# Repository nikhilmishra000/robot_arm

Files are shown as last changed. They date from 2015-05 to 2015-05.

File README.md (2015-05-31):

This is the CAD designs and some sample code for a 6 DOF robot arm I designed and built during fall 2014 while working for Professor Pieter Abbeel at the Robot Learning Lab at UC Berkeley.
It is made of laser-cut MDF and uses hobby servos for a total cost of ~$500. The SolidWorks files include some of the bearings, but no motors, angle-brackets, or springs (for counter-weights).

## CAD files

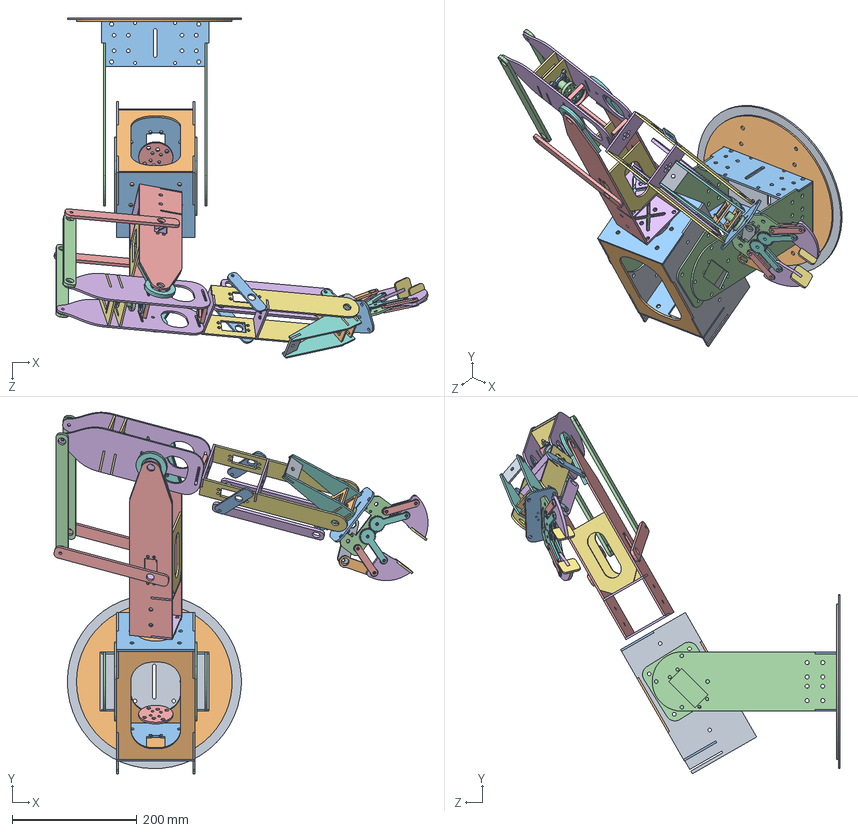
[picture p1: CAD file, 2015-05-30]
sw/arm.SLDASM
600.4 x 580.6 x 546.5 mm
base2
base1
base3 x 2
base4 x 2
upper_arm1 x 2
upper_arm2_(1,2) x 2
upper_arm3 x 2
upper_arm4 x 4
shoulder1 x 2
shoulder2 x 2
shoulder3_(1,2) x 2
shoulder4 x 2
shoulder5
elbow1 x 2
elbow2_(1,2) x 2
elbow3_(1,2,3)
1 x 1.245 super thin bearing x 2
.5 x .75 non flanged bearing x 2
servo shaft hub x 2
forearm1 x 2
forearm2 x 2
wrist1 x 2
wrist3
wrist2_(1,2) x 2
palm1
palm2
finger1 x 4
finger2 x 2
finger3 x 2
finger4 x 4
link1
link2
wrist_link2 x 2
elbow_link1 x 2
elbow_link2 x 2
wrist_link1 x 2

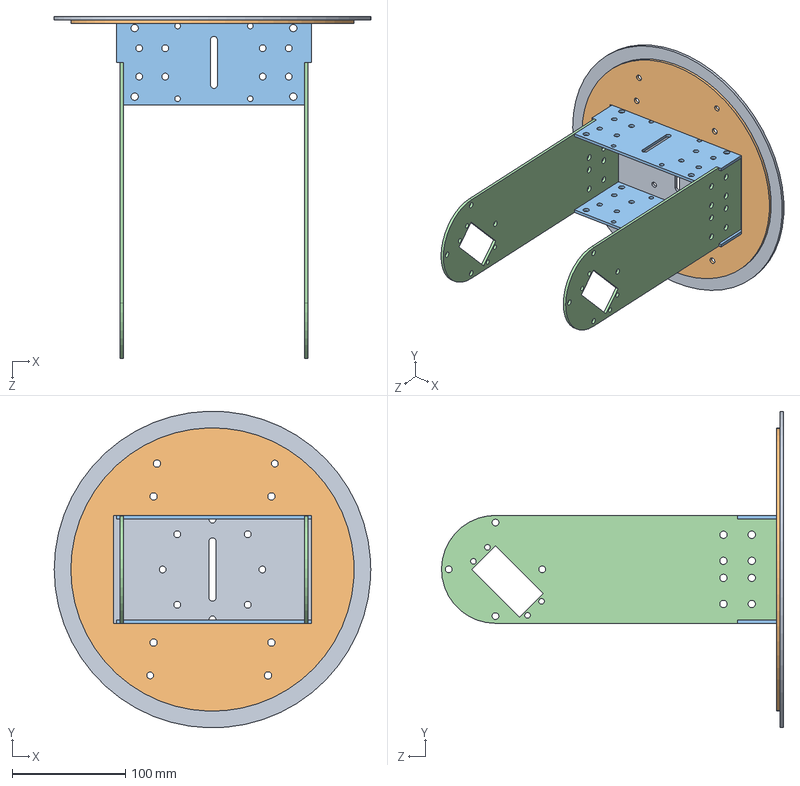
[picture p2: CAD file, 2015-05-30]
sw/base/BASE.SLDASM
279.4 x 279.3 x 301.8 mm
base2
base1
base3 x 2
base4 x 2

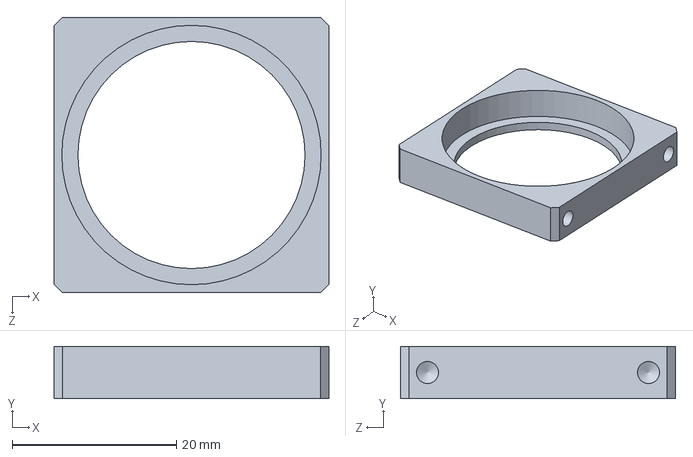
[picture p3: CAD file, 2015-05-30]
sw/bearings/bearing_mount2.SLDASM
33.5 x 6.35 x 33.5 mm

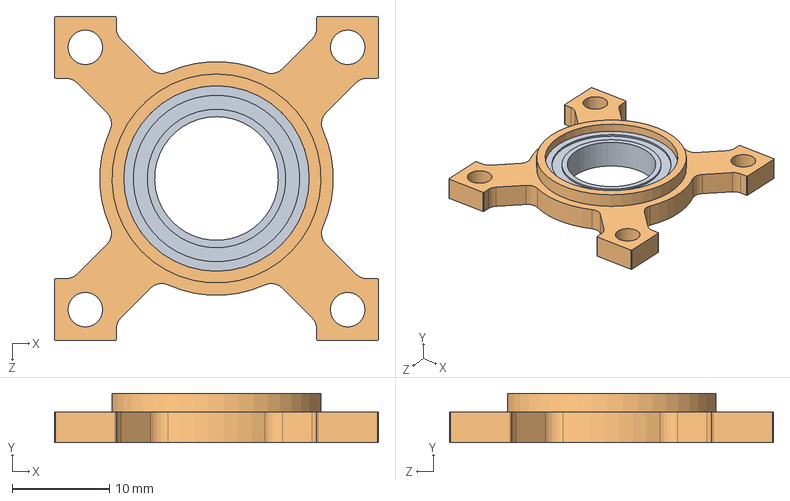
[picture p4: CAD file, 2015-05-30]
sw/bearings/bearing mount.SLDASM
33.3 x 5.08 x 33.3 mm
.5 x .75 non flanged bearing

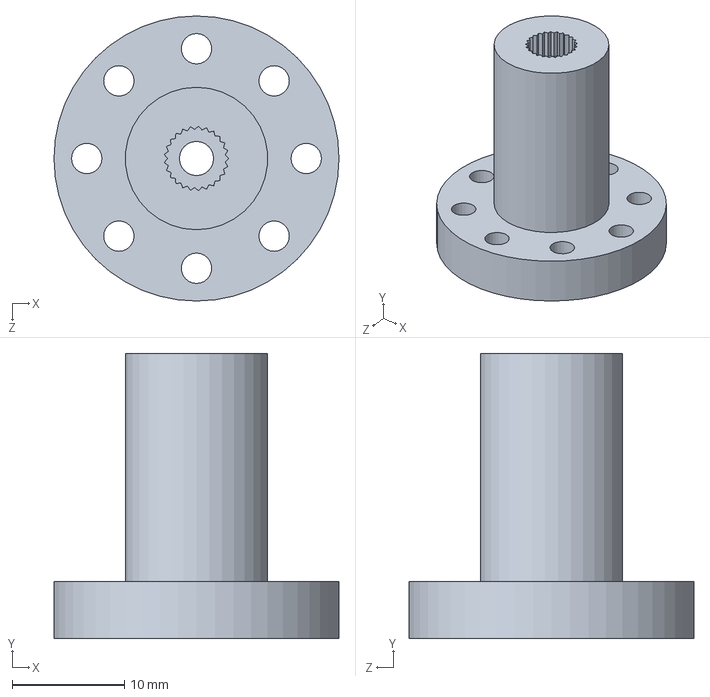
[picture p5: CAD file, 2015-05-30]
sw/bearings/servo shaft hub.SLDPRT
25.4 x 25.4 x 25.4 mm

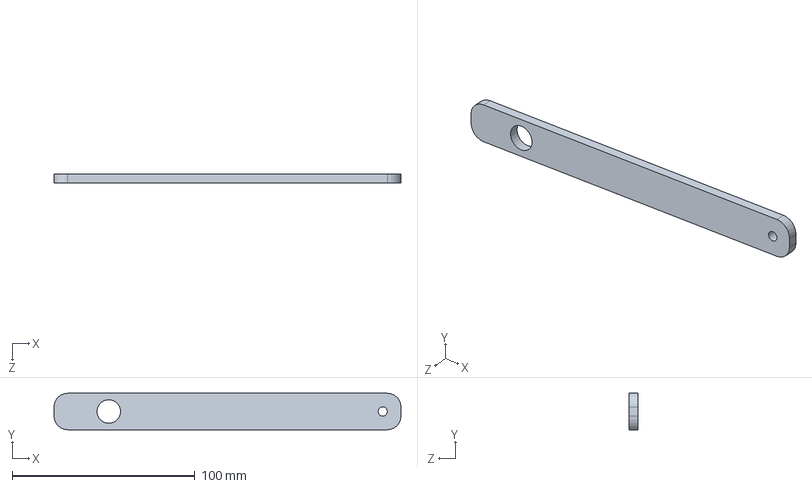
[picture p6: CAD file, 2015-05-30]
sw/elbow/elbow_link2.SLDPRT
190.0 x 20.0 x 5.00 mm

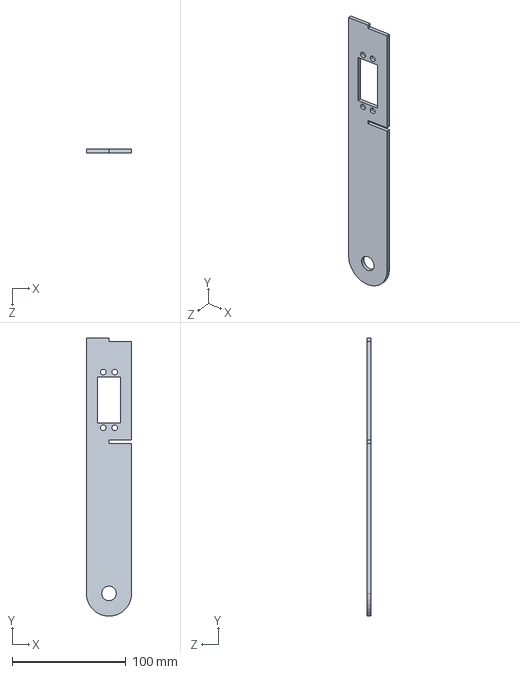
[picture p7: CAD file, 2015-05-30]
sw/forearm/forearm2.SLDPRT
40.0 x 244.7 x 3.10 mm

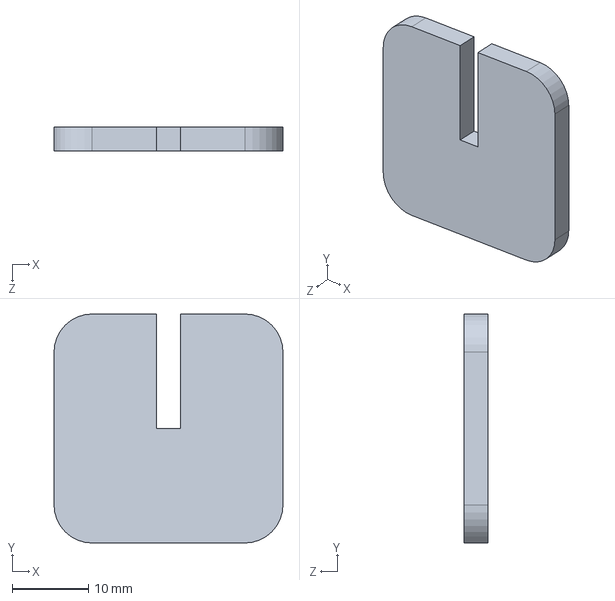
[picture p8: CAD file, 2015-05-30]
sw/gripper/finger3.SLDPRT
30.0 x 30.0 x 3.10 mm

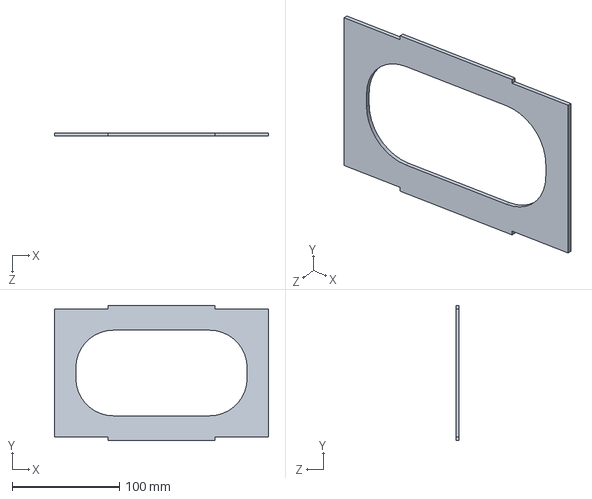
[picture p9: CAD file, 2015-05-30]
sw/shoulder/shoulder2.SLDPRT
200.0 x 126.2 x 3.10 mm

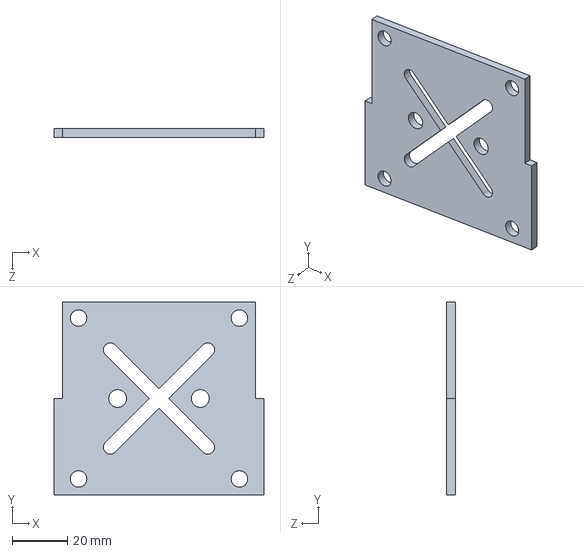
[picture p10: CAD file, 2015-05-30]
sw/upper_arm/upper_arm2_(1,2).SLDPRT
76.2 x 70.0 x 3.10 mm

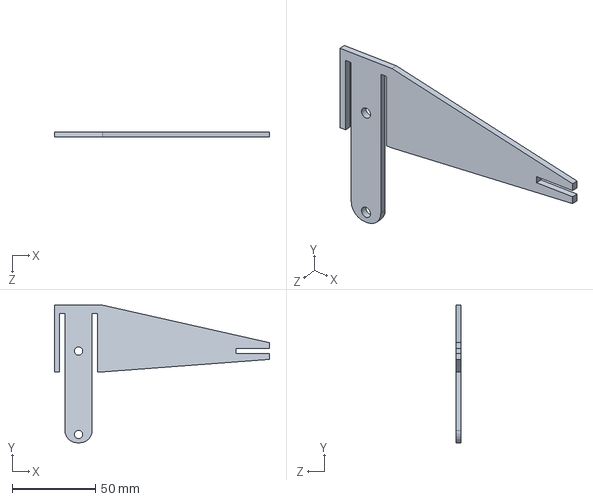
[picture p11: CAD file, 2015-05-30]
sw/wrist/wrist1.SLDPRT
128.8 x 82.5 x 3.10 mm

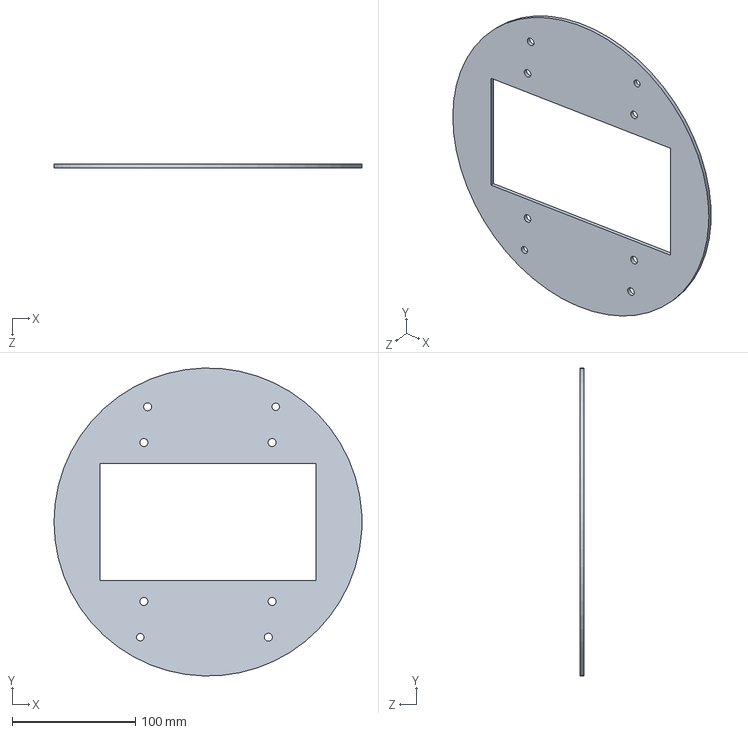
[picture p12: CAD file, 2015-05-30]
sw/base/base1.SLDPRT
250.0 x 249.9 x 3.00 mm

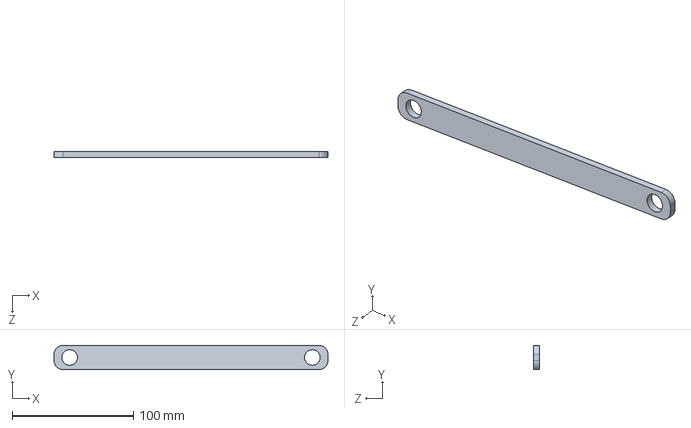
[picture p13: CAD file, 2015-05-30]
sw/elbow/elbow_link1.SLDPRT
225.8 x 20.0 x 5.00 mm

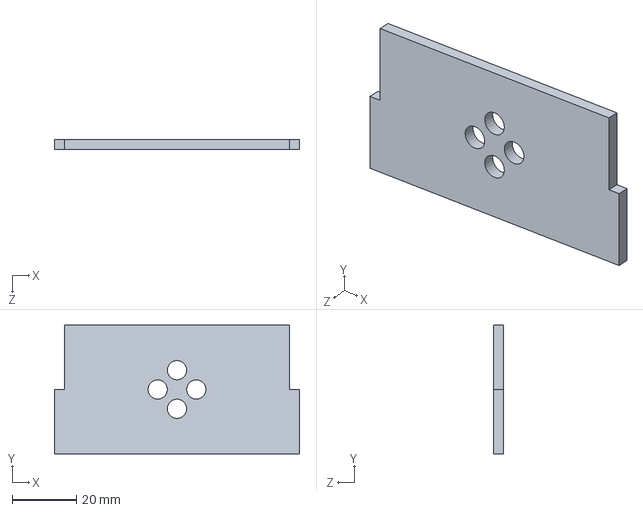
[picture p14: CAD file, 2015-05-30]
sw/forearm/forearm1.SLDPRT
76.2 x 40.0 x 3.10 mm

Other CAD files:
sw/bearings/.5 x .75 non flanged bearing.sldprt
sw/gripper/finger2.SLDPRT
sw/shoulder/shoulder5.SLDPRT
sw/upper_arm/upper_arm4.SLDPRT
sw/base/base2.SLDPRT
sw/base/base3.SLDPRT
sw/base/base4.SLDPRT
sw/bearings/1 x 1.245 super thin bearing.sldprt
sw/bearings/535118.sldprt
sw/bearings/535178.sldprt
sw/elbow/elbow1.SLDPRT
sw/elbow/elbow2_(1,2).SLDPRT
sw/elbow/elbow3_(1,2,3).SLDPRT
sw/gripper/finger1.SLDPRT
sw/gripper/finger4.SLDPRT
sw/gripper/link1.SLDPRT
sw/gripper/link2.SLDPRT
sw/gripper/palm1.SLDPRT
sw/gripper/palm2.SLDPRT
sw/shoulder/shoulder1.SLDPRT
sw/shoulder/shoulder3_(1,2).SLDPRT
sw/shoulder/shoulder4.SLDPRT
sw/upper_arm/upper_arm1.SLDPRT
sw/upper_arm/upper_arm3.SLDPRT
sw/wrist/wrist2_(1,2).SLDPRT
sw/wrist/wrist3.SLDPRT
sw/wrist/wrist_link1.SLDPRT
sw/wrist/wrist_link2.SLDPRT

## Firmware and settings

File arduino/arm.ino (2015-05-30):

#include <Servo.h>
#include "ServoPins.h"
#include "JointLimits.h"
#include "StatusCodes.h"

int status;
Servo gripper, wristRoll, wristPanL, wristPanR, elbowRoll, elbowPanL, elbowPanR, shoulderRoll, shoulderPanL, shoulderPanR;

void setup(){
  Serial.begin(9600);
  Serial.println("Started...");
  attachServos();
  //homePos();
  status = READY;
}

void loop(){
  if(status == READY){
      while(Serial.available()){
        int m = Serial.parseInt();
        char c = Serial.read();
        int t = Serial.parseInt();
        c = Serial.read();
        commandServo(DOFS[m],t);
      }
  }
}
      
////////////////////////////////////////////////////
void commandServo(int m, int p) {
  status = BUSY;
  switch (m) {

    case GRIPPER_PIN:
          if(p == 0){
            openGripper();
          } else if(p == 1){
            closeGripper();
          } else if (p >= GRIPPER_OPEN && p <= GRIPPER_CLOSED) {
            gripper.write(p);
          }
          break;


    case WRIST_ROLL_PIN:
      if (p >= WRIST_ROLL_MIN && p <= WRIST_ROLL_MAX) {
        wristRoll.write(p);
      }
      break;


    case WRIST_PAN_PINL:
      if (p >= WRIST_PAN_MIN && p <= WRIST_PAN_MAX) {
        wristPanL.write(p);
        wristPanR.write(180 - p);
      }
      break;


    case ELBOW_ROLL_PIN:
      if (p >= ELBOW_ROLL_MIN && p <= ELBOW_ROLL_MAX) {
        elbowRoll.write(p);
      }
      break;


    case ELBOW_PAN_PINL:
      if (p >= ELBOW_PAN_MIN && p <= ELBOW_PAN_MAX) {
        elbowPanL.write(p);
        elbowPanR.write(180 - p);
      }
      break;


    case SHOULDER_ROLL_PIN:
      if (p >= SHOULDER_ROLL_MIN && p <= SHOULDER_ROLL_MAX) {
        shoulderRoll.write(p);
      }
      break;
  
  case SHOULDER_PAN_PINL:
      if (p >= SHOULDER_PAN_MIN && p <= SHOULDER_PAN_MAX) {
        shoulderPanL.write(p);
        shoulderPanR.write(180-p);
      }
      break;

  default:
      Serial.print("No servo on pin ");
      Serial.println(m);
      break;
  }
  status = READY;
}

void openGripper() {
  gripper.write(GRIPPER_OPEN);
}

void closeGripper() {
  gripper.write(GRIPPER_CLOSED + 30);
}


void attachServos() {
  gripper.attach(GRIPPER_PIN);
  wristRoll.attach(WRIST_ROLL_PIN);
  wristPanL.attach(WRIST_PAN_PINL);
  wristPanR.attach(WRIST_PAN_PINR);
  elbowRoll.attach(ELBOW_ROLL_PIN);
  elbowPanL.attach(ELBOW_PAN_PINL);
  elbowPanR.attach(ELBOW_PAN_PINR);
  shoulderRoll.attach(SHOULDER_ROLL_PIN);
  shoulderPanL.attach(SHOULDER_PAN_PINL);
  shoulderPanR.attach(SHOULDER_PAN_PINR);
}

void homePos(){
  openGripper();
  commandServo(DOFS[0], 90);
  commandServo(DOFS[1], 90);
  commandServo(DOFS[2], 120);
  commandServo(DOFS[3], 70);
  commandServo(DOFS[4], 90);
  commandServo(DOFS[5], 90);
}

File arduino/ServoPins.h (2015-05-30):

// blue
const int GRIPPER_PIN = 2;

// green
const int WRIST_ROLL_PIN = 3;

// yellow, yellow
const int WRIST_PAN_PINL = 4;
const int WRIST_PAN_PINR = 5;

// orange
const int ELBOW_ROLL_PIN = 6;

// blue, blue
const int ELBOW_PAN_PINL = 7;
const int ELBOW_PAN_PINR = 8;

// green
const int SHOULDER_ROLL_PIN = 9;

// yellow, yellow
const int SHOULDER_PAN_PINL = 10;
const int SHOULDER_PAN_PINR = 11;

const int N = 7;

const int DOFS[N] = {SHOULDER_PAN_PINL, SHOULDER_ROLL_PIN,
                     ELBOW_PAN_PINL, ELBOW_ROLL_PIN,
                     WRIST_PAN_PINL, WRIST_ROLL_PIN,
                     GRIPPER_PIN};

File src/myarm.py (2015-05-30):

import numpy as np
from openravepy import *
from myarm_utils import *
import trajoptpy
import trajoptpy.kin_utils as ku
import serial
import json
import time

class MyArm():

	def __init__(self, path="../models/", bodies=["arm.xml","table.xml","object.xml"], view=True, connect=False):
		e = Environment()
		e.StopSimulation()
		for b in bodies:
			if not e.Load(path + b):
				raise RuntimeError(b + " not found")
		robot = e.GetRobots()[0]
		manip = robot.GetActiveManipulator()
		homeState =  [1.57, 1.9, 2.3, 1.25, 1.57, 1.4]
		robot.SetDOFValues(homeState, manip.GetArmIndices())
		self.env, self.robot, self.manip, self.homeJoints = e, robot, manip, homeState
		
		if connect:
			self.attachPort()
		if view:
			e.SetViewer('qtcoin')
		self.openGrip()

	def home(self):
		self.sendJointState(self.homeJoints)
	
	def back(self):
		if hasattr(self, "reverse"):
			self.followTraj(self.reverse)
	
	def followTraj(self, traj, delay=0.05):
		self.reverse = []
		for step in traj:
			self.reverse = [step] + self.reverse
			self.sendJointState(step)
			self.robot.SetDOFValues(step, self.manip.GetArmIndices())
			time.sleep(delay)

	def moveJoint(self, m, p):
		cmd = str(m) + ',' + str(p) + ','
		self.port.write(cmd)

	def sendJointState(self, joints):
		if len(joints) == len(self.manip.GetArmIndices()):
			self.robot.SetDOFValues(joints, self.manip.GetArmIndices())
			if hasattr(self, 'port'):
				joints =  map(lambda x: int(round(x)), np.degrees(joints))
				for j in range(len(joints)):
					self.moveJoint(j, joints[j])
		else:
			print "wrong number of joints"

	def plotGrip(self):
		self.P = self.env.plot3(points=self.manip.GetTransform().dot(O)[:3],pointsize=15)
		self.P.SetShow(True)

	def jointState(self):
		return self.robot.GetDOFValues(self.manip.GetArmIndices())	

	def readMsg(self):
		if hasattr(self, 'port'):
			msg = '';
			c = self.port.read()
			while c != '':
				msg += c;
				c = self.port.read()
			print msg
			
	def attachPort(self, name='/dev/ttyACM0', baud=9600):
		self.port = serial.Serial(name, baud, timeout=1)
		self.readMsg()
		atexit.register(self.closePort)
		self.sendJointState(self.homeJoints)

	def closePort(self):
		if hasattr(self, 'port'):
			self.port.close()
			print "closed serial connection"

	def openGrip(self):
		if hasattr(self, 'port'):
			self.moveJoint(GRIPPER_INDEX, 0)
		self.robot.SetDOFValues([GRIPPER_OPEN_RAD], self.manip.GetGripperIndices())

	def closeGrip(self):
		if hasattr(self, 'port'):
			self.moveJoint(GRIPPER_INDEX, 1)
		self.robot.SetDOFValues([GRIPPER_CLOSED_RAD], self.manip.GetGripperIndices())

	def computeTrajToPose(self,target):
		params = myIK(target)
		
		request = {
		  "basic_info" : {
		    "n_steps" : 10,
		    "manip" : "grip",
		    "start_fixed" : True
		  },
		  "costs" : [
		  {
		    "type" : "joint_vel",
		    "params": {"coeffs" : [1]}
		  },
		  {
		    "type" : "collision",
		    "name" : "cont_coll",
		    "params" : {
		      "continuous" : True,
		      "coeffs" : [20],
		      "dist_pen" : [0.025]
		    },    
		  }
		  ],
		  "constraints" : [
		  {
		    "type" : "pose",
		    "params" : {"xyz" : params['xyz'].tolist(),
				"wxyz" : params['quat'].tolist(),
				"link" : "Palm",
				"timestep" : 9
			    }
		  }
		  ],
		  "init_info" : {
		      "type" : "straight_line",
		      "endpoint" : params['joints'].tolist()
		  }
		}
		s = json.dumps(request)
		prob = trajoptpy.ConstructProblem(s, self.env)
		t_start = time.time()
		result = trajoptpy.OptimizeProblem(prob)
		t_elapsed = time.time() - t_start
		print "optimization took %.3f seconds"%t_elapsed
		return result.GetTraj(), params

if __name__ == "__main__":
	arm = MyArm(view=True, connect=True)
	obj = arm.env.GetKinBody("Object")

	x,y,z = obj.GetTransform()[:3,3]
	target = np.array([0, 0, 1, 0, 1, 0, x, y, z])


	traj, params = arm.computeTrajToPose(target)
	arm.followTraj(traj)

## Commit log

2015-05-30 created repo and added files
    [.5 x .75 non flanged bearing.sldprt, 1 x 1.245 super thin bearing.sldprt, 535118.sldprt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]
2015-05-31 added cad, openrave models and arduino/python code
